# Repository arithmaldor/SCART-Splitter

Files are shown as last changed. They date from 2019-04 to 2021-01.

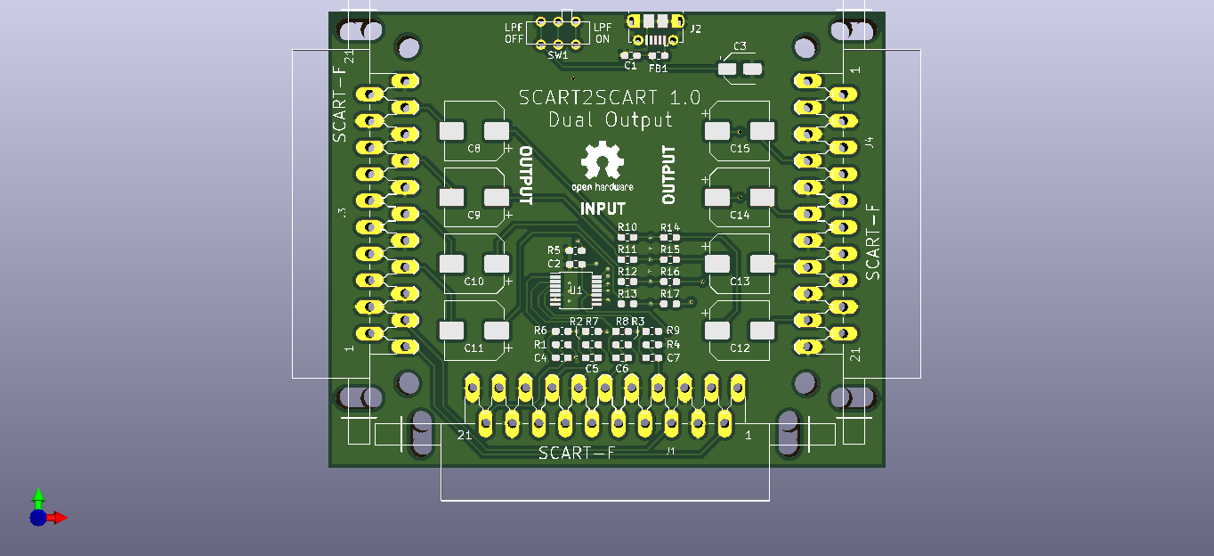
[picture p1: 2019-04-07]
Renders/Top.png

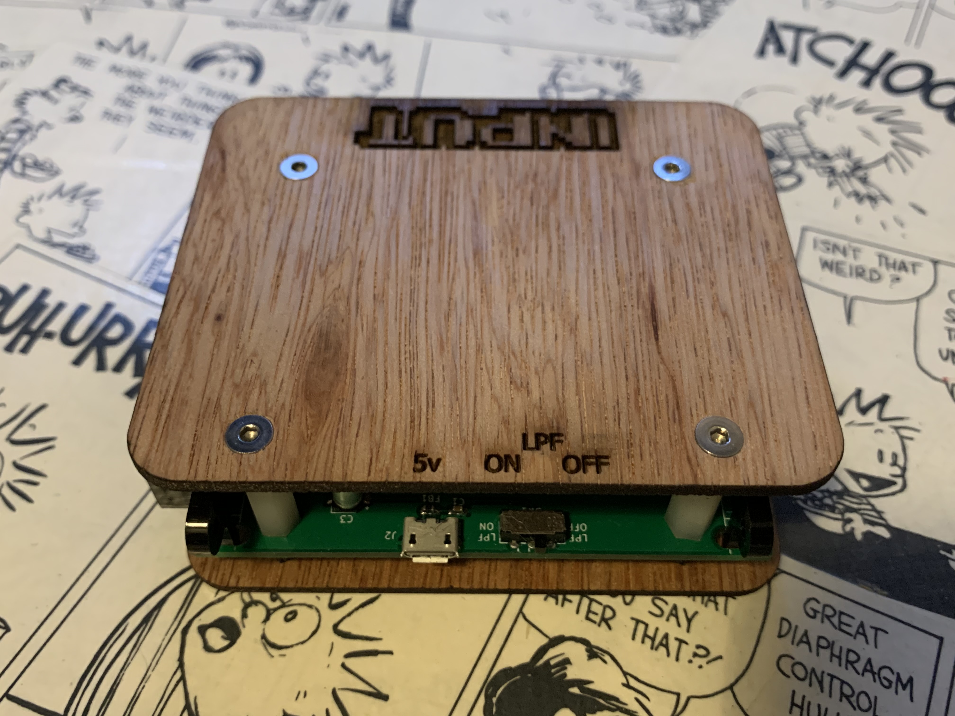
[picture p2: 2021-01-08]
Case/Photos/Case-Top-Back.jpg

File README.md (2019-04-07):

# SCART-Splitter
This is a simple SCART splitter based on the THS7374.
The circuit is is AC-bias mode so component video will be properly driven. It can be easily adapted for a variety of connectors; RCA, BNC, VGA, whatever you need.
Audio is simply connected to both outputs so might be a bit quiet.

# Thanks
This was loosely based on Voultar's open source [Dual Output board.](https://oshpark.com/shared_projects/6o0jvLnD)
Special thanks also to RetroRGB; thanks to examining the 2DVI boards I gained a better understanding of these circuits.

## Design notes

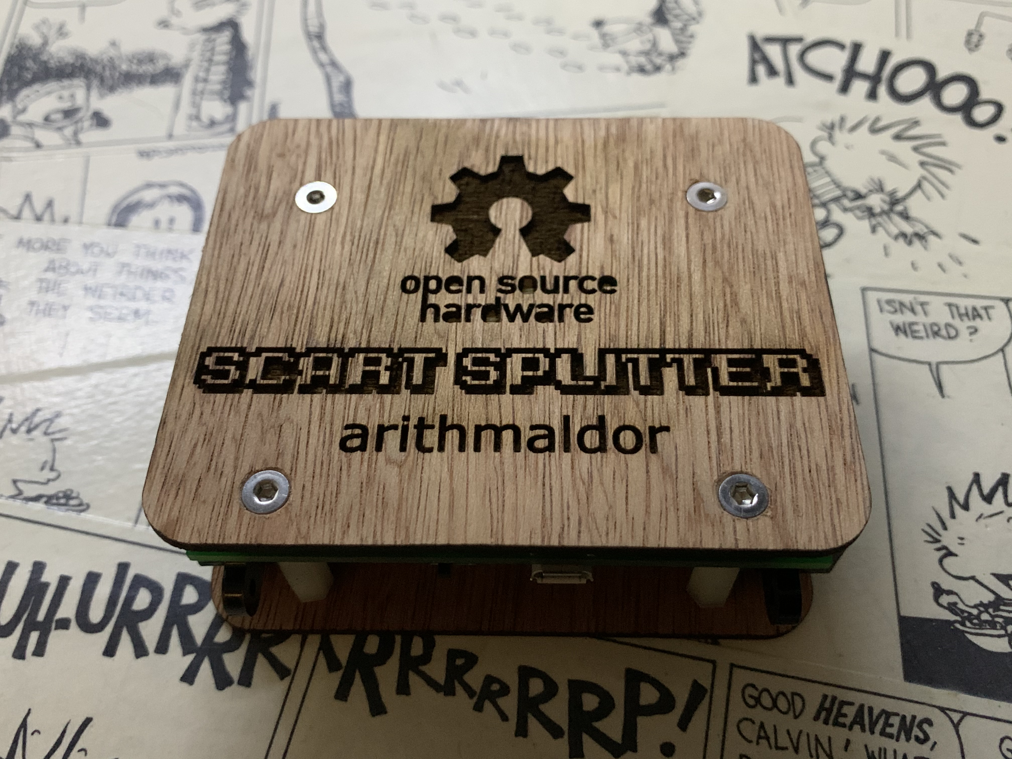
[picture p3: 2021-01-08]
Case/Photos/Case-Bottom.jpg

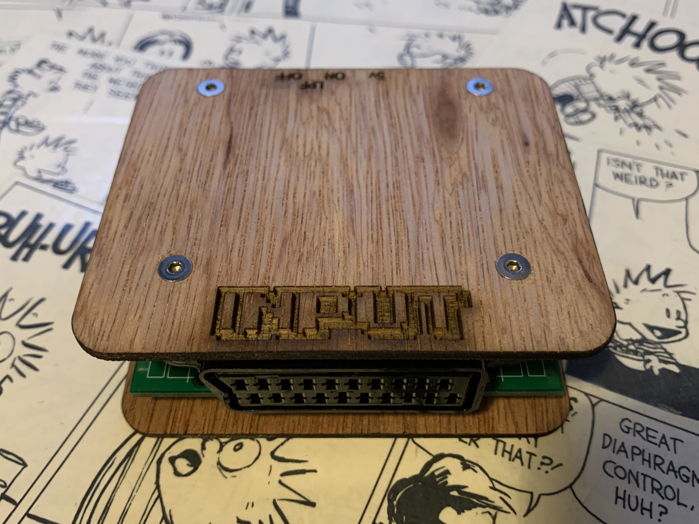
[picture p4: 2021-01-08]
Case/Photos/Case-Top-Front.jpg

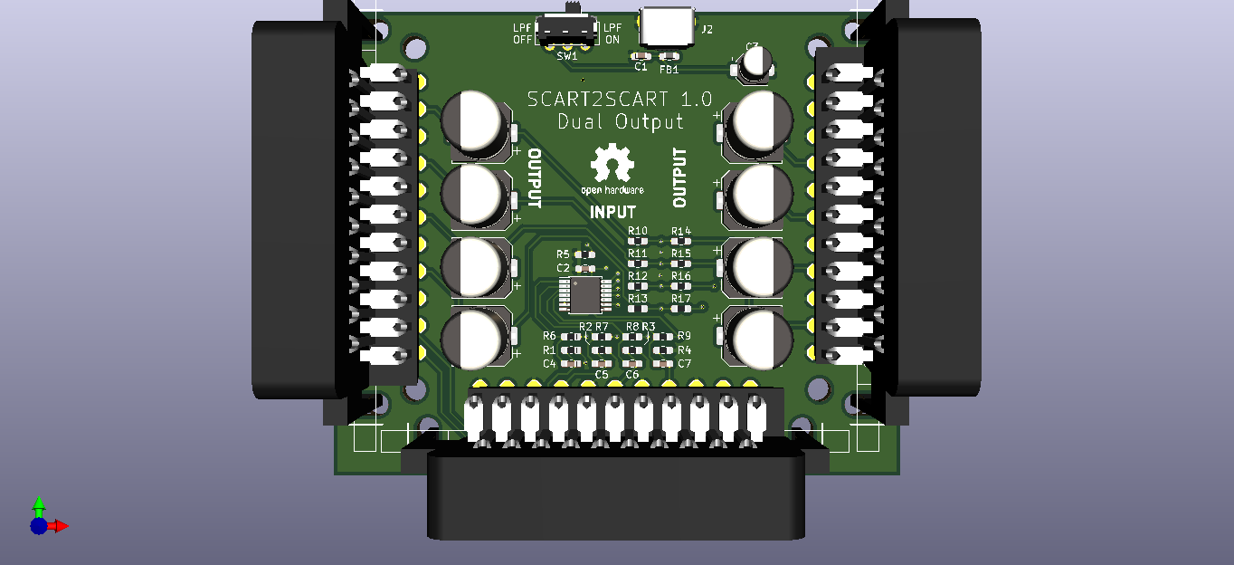
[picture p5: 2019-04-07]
Renders/Top 3D.png

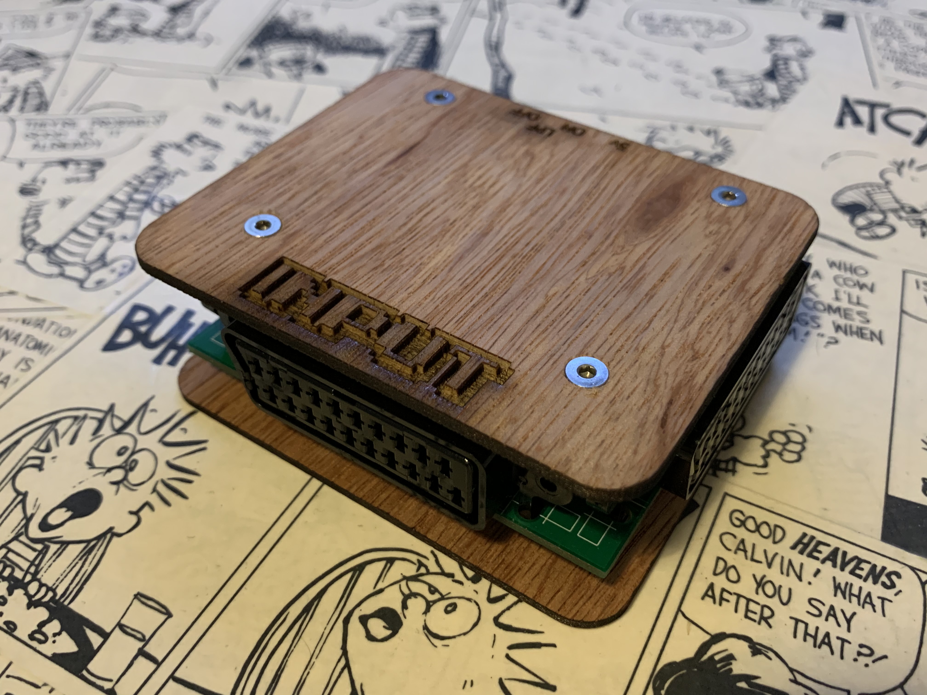
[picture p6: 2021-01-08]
Case/Photos/Case-Top-Angled.jpg

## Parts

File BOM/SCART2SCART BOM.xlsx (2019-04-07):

Qty | Ref(s) | Value | Footprint | Description | Note | Digikey | Arrow | LCSC | Other
1 | C1 | 10nF | 0603 | Ceramic 50V |  | https://www.digikey.com/product-detail/en/samsung-electro-mechanics/CL10B103KB8NCNC/1276-1921-1-ND/3890007 | https://www.arrow.com/en/products/cc0603krx7r9bb103/yageo | https://lcsc.com/product-detail/Others_Samsung-Electro-Mechanics_CL10B103KB8NFNC_Samsung-Electro-Mechanics-CL10B103KB8NFNC_C307477.html
5 | C2, C4-7 | 100nF | 0603 | Ceramic 50V |  | https://www.digikey.com/product-detail/en/CL10F104ZO8NNNC/1276-1258-1-ND/3889344/ | https://www.arrow.com/en/products/cl10f104zo8nnnc/samsung-electro-mechanics | https://lcsc.com/product-detail/Multilayer-Ceramic-Capacitors-MLCC-SMD-SMT_100nF-104-10-50V_C14663.html
1 | C3 | 10uF | 4x5.4 | Elec. 25V |  | https://www.digikey.com/product-detail/en/panasonic-electronic-components/EEE-FK1E100R/PCE3795CT-ND/766171 | https://www.arrow.com/en/products/eeefk1e100r/panasonic | https://lcsc.com/product-detail/Others_PANASONIC-EEE1EA100WAR_C336730.html
8 | C8-15 | 220uF | 8x10 | Elec. 25V |  | https://www.digikey.com/product-detail/en/nichicon/UUD1E221MNL1GS/493-2278-1-ND/590253 | https://www.arrow.com/en/products/uud1e221mnl1gs/nichicon | https://lcsc.com/product-detail/Others_Nichicon_UCD1E221MCL1GS_Nichicon-UCD1E221MCL1GS_C250944.html
12 | R1-4, 10-17 | 75R | 0603 | 1% |  | https://www.digikey.com/product-detail/en/rohm-semiconductor/ESR03EZPF75R0/RHM75.0ADCT-ND/1983773 | https://www.arrow.com/en/products/erj-3ekf75r0v/panasonic | https://lcsc.com/product-detail/Chip-Resistor-Surface-Mount_75R-75R0-1_C112309.html
1 | R5 | 100K | 0603 | 1% |  | https://www.digikey.com/product-detail/en/yageo/RC0603FR-07100KL/311-100KHRCT-ND/729836 | https://www.arrow.com/en/products/erj-3ekf1003v/panasonic | https://lcsc.com/product-detail/Chip-Resistor-Surface-Mount_100KR-1003-1_C14675.html
4 | R6-9 | 5.6M | 0603 | 1% |  | https://www.digikey.com/product-detail/en/vishay-dale/CRCW06035M60FKEA/541-5.60MHCT-ND/1180237 | https://www.arrow.com/en/products/crcw06035m60fkea/vishay | https://lcsc.com/product-detail/Chip-Resistor-Surface-Mount_5-6MR-5604-1_C103715.html
1 | FB1 | 220R | 0603 | Ferrite Bead |  | https://www.digikey.com/product-detail/en/tdk-corporation/MPZ1608S221ATA00/445-1565-1-ND/571895 | https://www.arrow.com/en/products/mpz1608s221ata00/tdk | https://lcsc.com/product-detail/Ferrite-Beads-And-Chips_TDK_MPZ1608S221ATA00_220R-25-at100MHz_C76815.html
1 | U1 | THS7374 | TSSOP-14 |  |  | https://www.digikey.com/product-detail/en/texas-instruments/THS7374IPWR/296-41661-1-ND/5224405 | https://www.arrow.com/en/products/ths7374ipw/texas-instruments |  | https://console5.com/store/ths7374-4-channel-sdtv-hdtv-video-amplifier-rgb-ths7374ipwr-tssop.html
3 | J1, 3, 4 | SCART | Right Angle |  |  |  |  |  | https://console5.com/store/female-scart-jp21-through-hole-pcb-mount-21-pin-connector-right-angle.html
1 | J2 | microUSB | Right Angle | Molex Style |  | https://www.digikey.com/product-detail/en/molex/1050170001/WM1399CT-ND/2350885 | https://www.arrow.com/en/products/1050170001/molex | https://lcsc.com/product-detail/USB-Connectors_Jing-Extension-of-the-Electronic-Co-LCSC-MICRO-USB-5S-B-Type-horns-High-temperature_C10418.html
1 | SW1 | DPDT | THT RA |  |  | https://www.digikey.com/product-detail/en/c-k/JS202011AQN/401-2000-ND/1640096 | https://www.arrow.com/en/products/js202011aqn/ck | https://lcsc.com/product-detail/Toggle-Switches_C-K_JS202011AQN_C-K-JS202011AQN_C221662.html

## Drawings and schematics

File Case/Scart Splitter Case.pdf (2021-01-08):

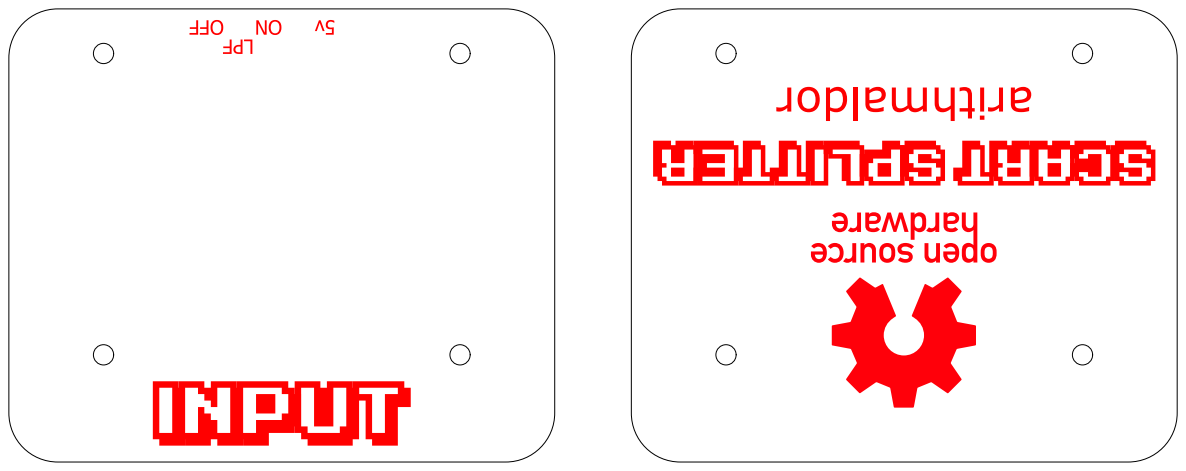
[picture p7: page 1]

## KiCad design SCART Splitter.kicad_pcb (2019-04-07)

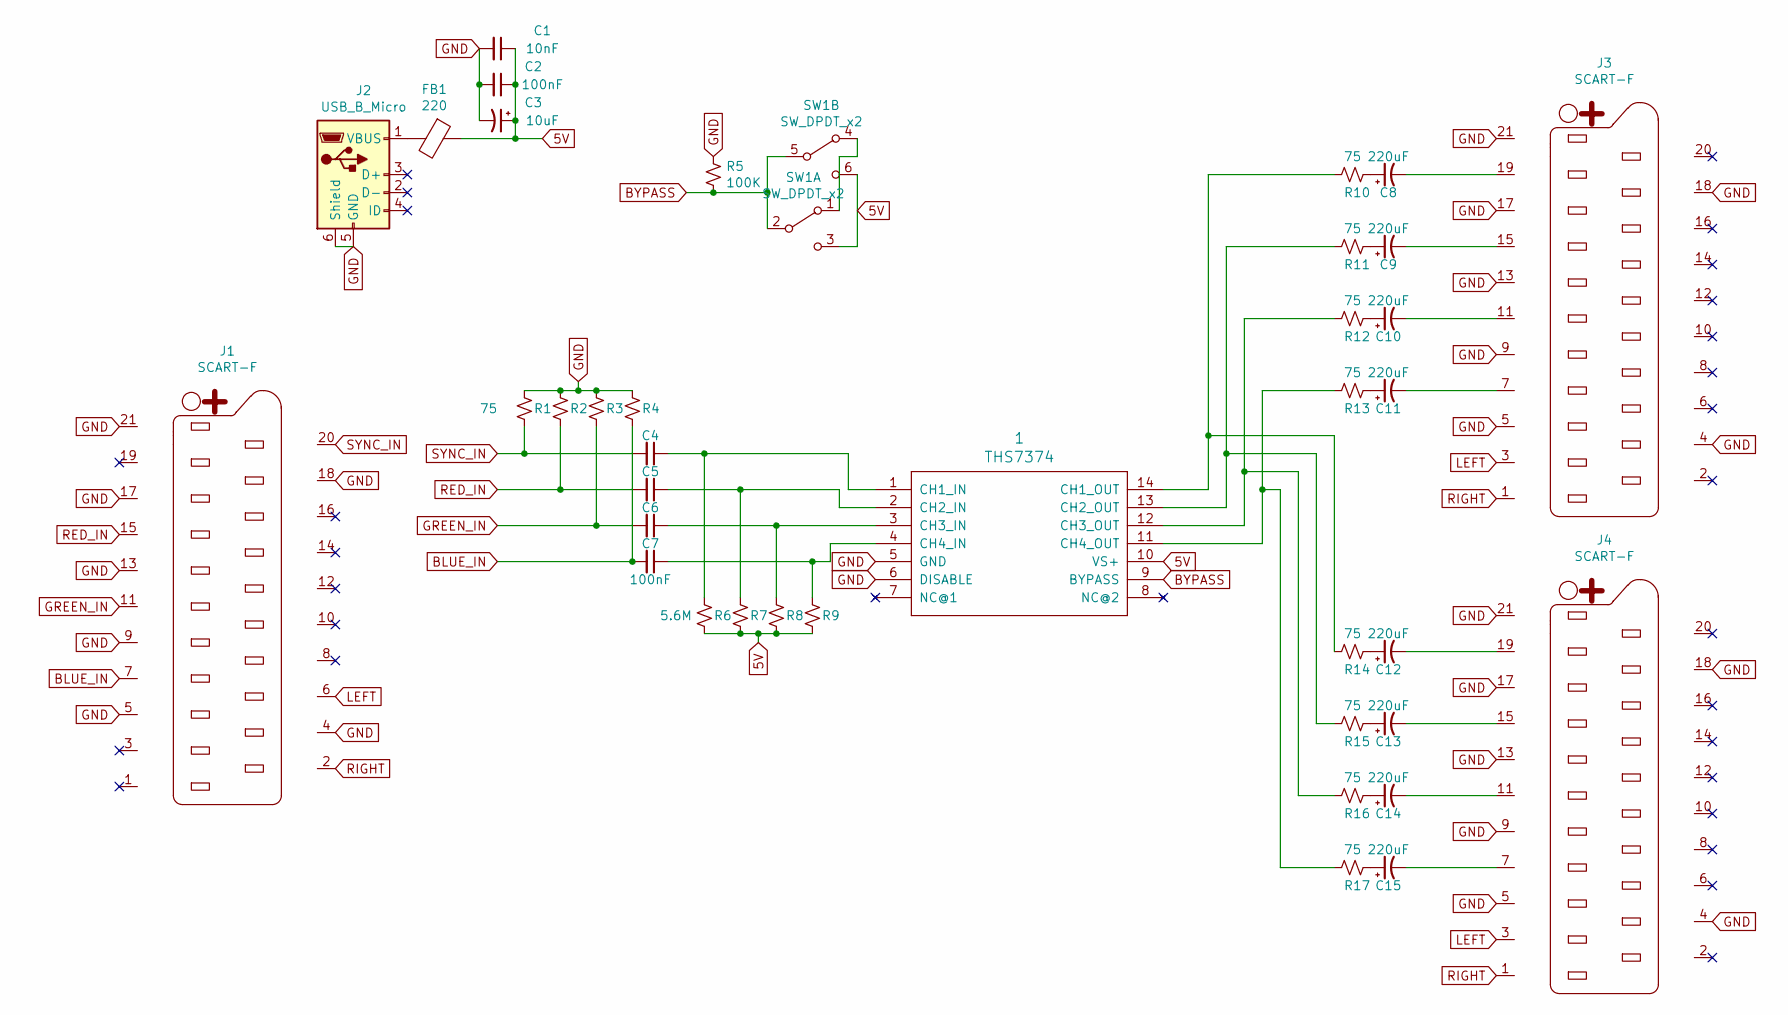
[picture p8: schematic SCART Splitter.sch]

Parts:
1: THS7374; TSSOP-14_4.4x5mm_P0.65mm
C1: 10nF; C_0603_1608Metric_Pad1.05x0.95mm_HandSolder
C2, C4, C5, C6, C7: 100nF; C_0603_1608Metric_Pad1.05x0.95mm_HandSolder
C3: 10uF; CP_Elec_4x5.4
C8, C9, C10, C11, C12, C13, C14, C15: 220uF; CP_Elec_8x10
FB1: 220; L_0603_1608Metric_Pad1.05x0.95mm_HandSolder
J1, J3, J4: SCART-F
J2: USB_B_Micro; USB_Micro-B_Molex-105017-0001
R1, R2, R3, R4, R10, R11, R12, R13, R14, R15, R16, R17: 75; R_0603_1608Metric_Pad1.05x0.95mm_HandSolder
R5: 100K; R_0603_1608Metric_Pad1.05x0.95mm_HandSolder
R6, R7, R8, R9: 5.6M; R_0603_1608Metric_Pad1.05x0.95mm_HandSolder
SW1: SW_DPDT_x2; JS202011

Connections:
5V: 1.10 (VS+), C1.1, C2.1, C3.1, FB1.1, R6.2, R7.2, R8.2, R9.2, SW1.3 (C), SW1.6 (C); also elsewhere on the board
BLUE_IN: C7.2, J1.7, R4.2
BYPASS: 1.9 (BYPASS), R5.2, SW1.2 (B), SW1.5 (B); also elsewhere on the board
GND: 1.5 (GND), 1.6 (DISABLE), C1.2, C2.2, C3.2, J1.4, J1.5, J1.9, J1.13, J1.17, J1.18, J1.21, J2.5 (GND), J2.6 (Shield), J3.4, J3.5, J3.9, J3.13, J3.17, J3.18, J3.21, J4.4, J4.5, J4.9, J4.13, J4.17, J4.18, J4.21, R1.1, R2.1, R3.1, R4.1, R5.1; also elsewhere on the board
GREEN_IN: C6.2, J1.11, R3.2
LEFT: J1.6, J3.3, J4.3
unnamed 6: 1.1 (CH1_IN), C4.1, R6.1; also elsewhere on the board
unnamed 7: 1.2 (CH2_IN), C5.1, R7.1; also elsewhere on the board
unnamed 8: 1.3 (CH3_IN), C6.1, R8.1; also elsewhere on the board
unnamed 9: 1.4 (CH4_IN), C7.1, R9.1; also elsewhere on the board
unnamed 12: 1.11 (CH4_OUT), R13.2, R17.2; also elsewhere on the board
unnamed 13: 1.12 (CH3_OUT), R12.2, R16.2; also elsewhere on the board
unnamed 14: 1.13 (CH2_OUT), R11.2, R15.2; also elsewhere on the board
unnamed 15: 1.14 (CH1_OUT), R10.2, R14.2; also elsewhere on the board
unnamed: C8.1, R10.1
unnamed: C8.2, J3.19
unnamed: C9.1, R11.1
unnamed: C9.2, J3.15
unnamed: C10.1, R12.1
unnamed: C10.2, J3.11
unnamed: C11.1, R13.1
unnamed: C11.2, J3.7
unnamed: C12.1, R14.1
unnamed: C12.2, J4.19
unnamed: C13.1, R15.1
unnamed: C13.2, J4.15
unnamed: C14.1, R16.1
unnamed: C14.2, J4.11
unnamed: C15.1, R17.1
unnamed: C15.2, J4.7
unnamed: FB1.2, J2.1 (VBUS)
unnamed: SW1.1 (A), SW1.4 (A)
RED_IN: C5.2, J1.15, R2.2
RIGHT: J1.2, J3.1, J4.1
SYNC_IN: C4.2, J1.20, R1.2

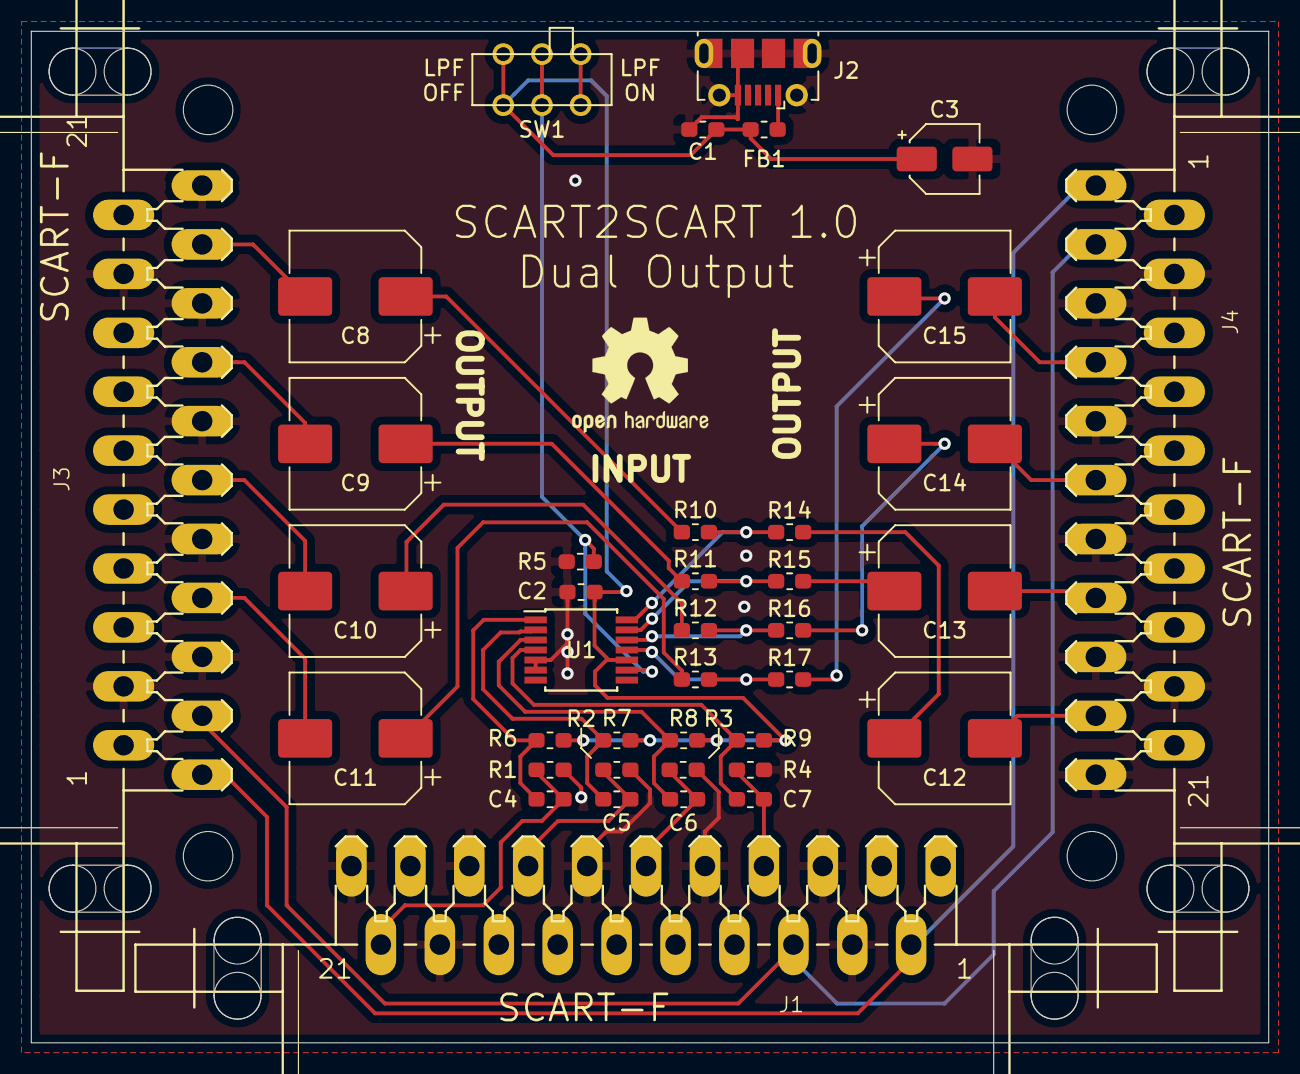
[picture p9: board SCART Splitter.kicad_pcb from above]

Board: 2 copper layers, 80.0 x 65.4 mm, 39 parts (0 on the bottom side), 35 nets.

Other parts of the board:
U1: THS7374; TSSOP-14_4.4x5mm_P0.65mm

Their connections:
5V: U1.10; also elsewhere on the board
BYPASS: U1.9; also elsewhere on the board
GND: U1.5, U1.6; also elsewhere on the board
unnamed 6: U1.1; also elsewhere on the board
unnamed 7: U1.2; also elsewhere on the board
unnamed 8: U1.3; also elsewhere on the board
unnamed 9: U1.4; also elsewhere on the board
unnamed 12: U1.11; also elsewhere on the board
unnamed 13: U1.12; also elsewhere on the board
unnamed 14: U1.13; also elsewhere on the board
unnamed 15: U1.14; also elsewhere on the board

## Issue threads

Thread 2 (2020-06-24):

Direction of Scart leads.

mmmonkeygrimes, 2020-06-24:
Possible optional pin header with all the signals of one of the Scart outputs on, would all to link up two boards and have one output Scart socket upside down.

Sounds odd, but allow to the 2 output Scart leads to come from the same direction.

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

Rather than the current setup

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

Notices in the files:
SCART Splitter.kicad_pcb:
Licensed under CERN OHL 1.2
